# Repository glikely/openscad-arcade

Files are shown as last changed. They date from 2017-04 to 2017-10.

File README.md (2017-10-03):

# OpenSCAD Arcade Modeling

This project contains models for designing and building arcade cabinets.

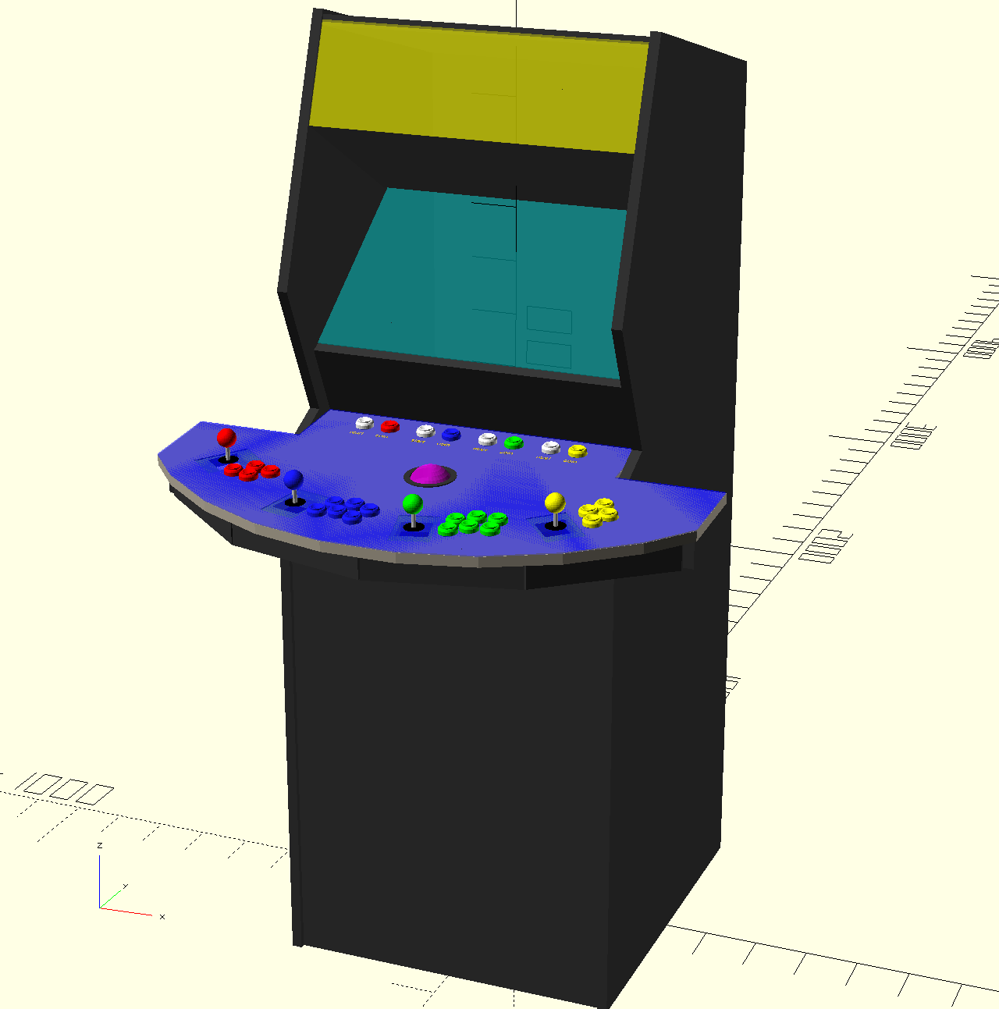
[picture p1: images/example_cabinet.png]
Arcade Panel


## Features

- Simple models for arcade controls: buttons, joysticks and trackballs
- Automatic generation of cutouts on control panel where controls are placed
- Support for multi layer control panel construction. ie. an MDF panel with an
  acrylic top sheet.
- Configurable for multiple players
- Countersunk joystick mounting for completely flat panels
- Output of .dxf files for use on a laser cutter.

## Build instructions

Installing OpenSCAD and opening the .scad files in this project should be all you
need to do to view the models.
You can get the latest release of OpenSCAD on the OpenSCAD website:
http://www.openscad.com

## Viewing the models

All of the model files can be viewed directly in OpenSCAD to see
examples of the models. The following libraries are included in this
repo:

- [controls.scad](controls.scad) - Models of common arcade controls.
  Currently implements a generic joystick, 28mm arcade buttons, and the
  Ultimarc U-Trak trackball. Also implements the concept of "control
  clusters" which is a set of controls clustered together in a specific
  orientation. ex. The joystick and buttons for a single player.
- [control_panel.scad](control_panel.scad) - Creates a control panel
  from one or more sheet materials (ie. MDF, perspex, etc) and places a
  configurable number of control clusters and start/coin buttons.
- [control_box.scad](control_box.scad) - Designs a custom enclosure box
  around a control panel generated by control_panel.scad.
- [cabinet.scad](cabinet.scad) - Simple model of a full size arcade
  cabinet using control_box and control_panel. Fun fact: model is based
  on a vintage "Track & Field" machine.

## Creating your own project

[example_2player_box.scad](example_2player_box.scad) shows how you can
use this library for your own custom arcade control box. To create your
own project, copy this file and add your new project to the Makefile.
When you type 'make', OpenSCAD will output a .dxf file with the layers
needed to lasercut your custom panel. (As-yet untested. You have been
warned!)

## Using the output

This project outputs design files that can be either directly laser cut on
materials (ex. acrylic & MDF),
or used to create cutting guides for materials that cannot be laser cut (ex.
plywood).
Viewing a project file (see example_*.scad) in OpenSCAD will show the 3D model.
To produce manufacturing artifacts change the value of OUTPUT_MODE to either
"lasercut" or "dimensions".

## TODO

The following features still need to be implemented

- PDF output of control panel layout to be used as template for graphics design
- Flattened layout of cabinet panels to use as cutting guide
- Support for side mounted pinball buttons
- Model "spinner" controls
- Model coin slots/door
- Model control boards and mounts
- Model speakers
- Add mounting holes for joysticks
- Allow vertical/horizontal/angle adjustment on control cluster placement instead
  of fixed by the formula.
- Allow 2 rows of control clusters

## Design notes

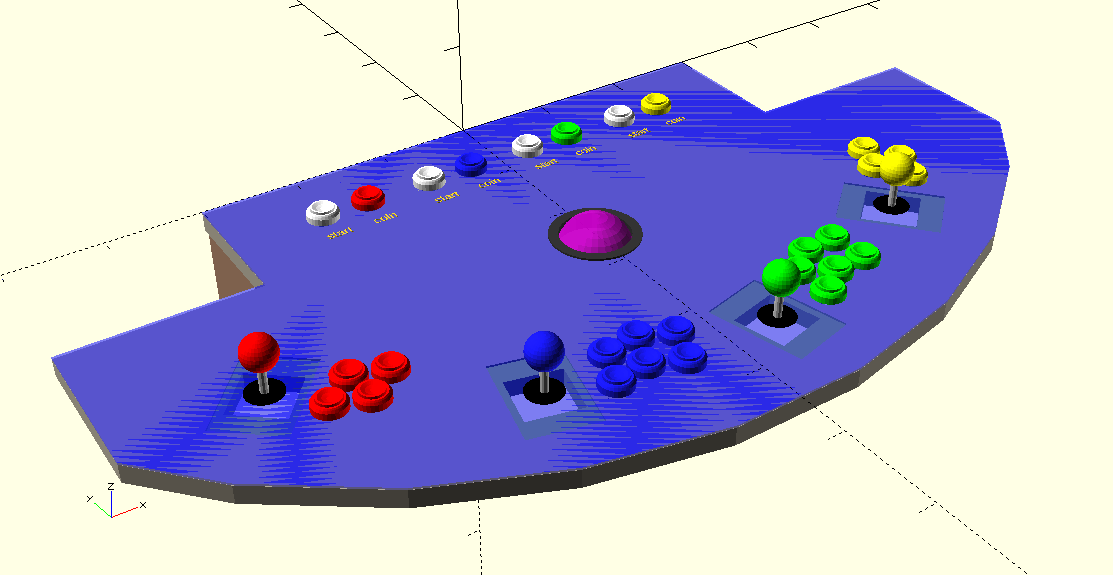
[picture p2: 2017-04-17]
images/example_panel.png

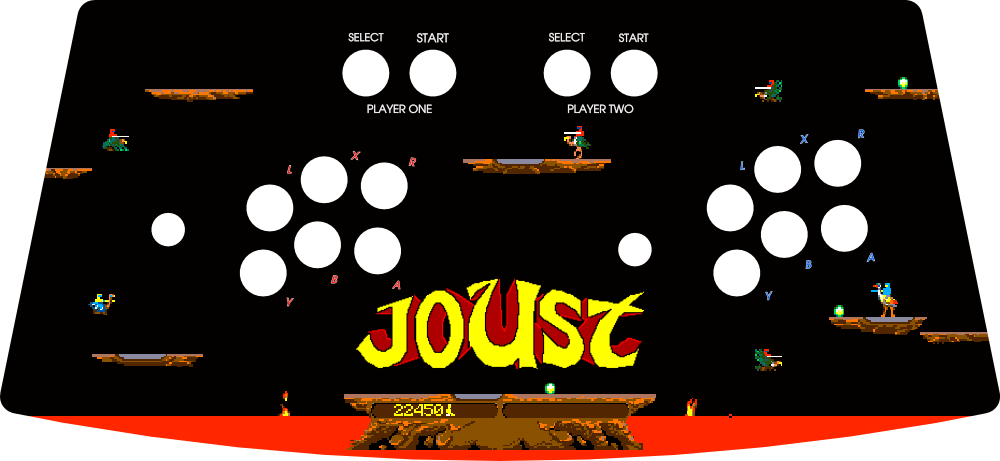
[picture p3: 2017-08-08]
2player_project/example_2player_box-vinyl-supernes.png

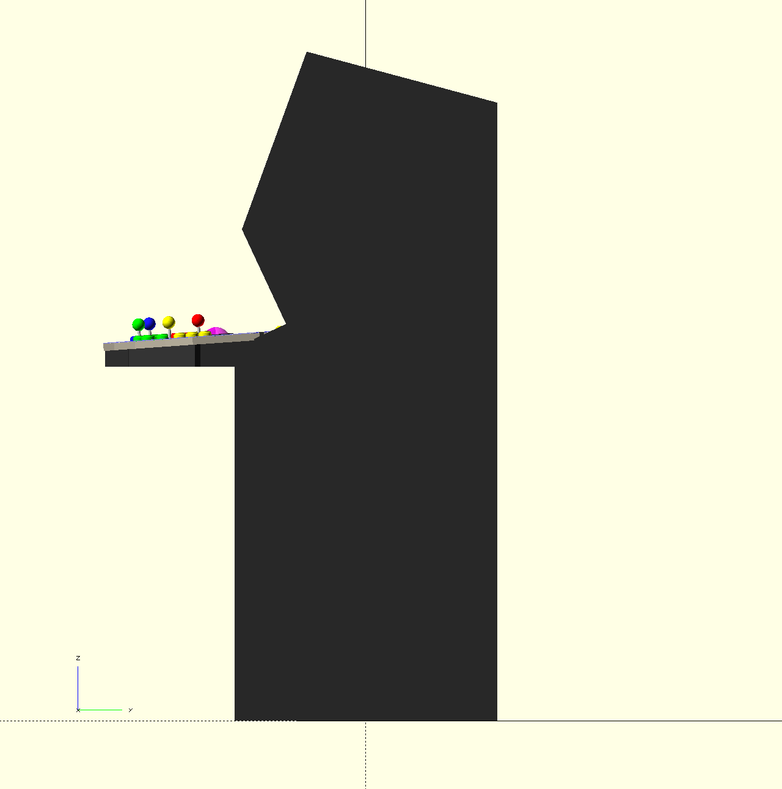
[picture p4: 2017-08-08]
2player_project/example_cabinet_side.png

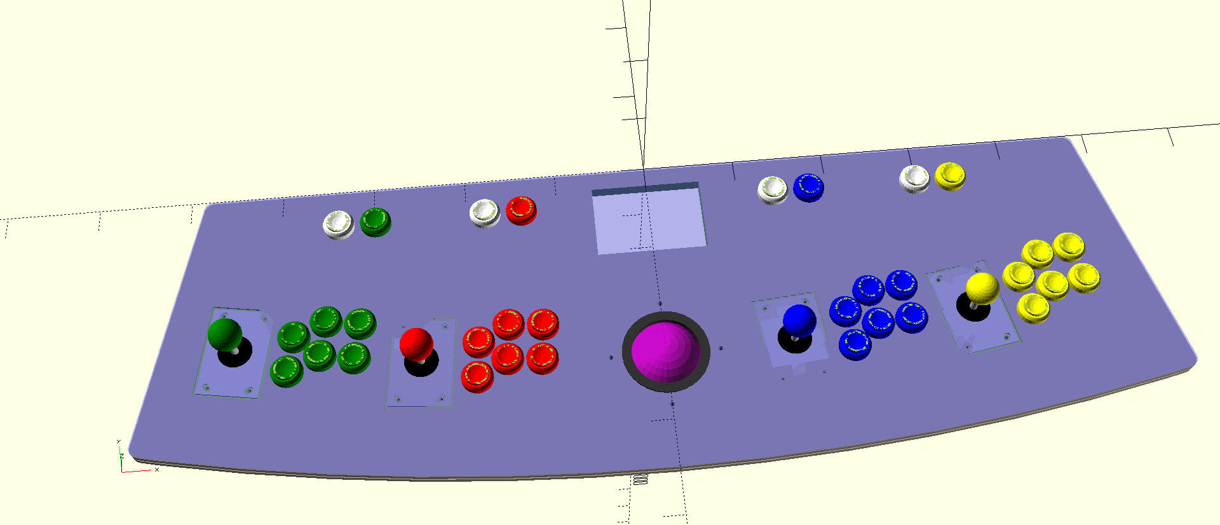
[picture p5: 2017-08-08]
2player_project/example_4player_box.png

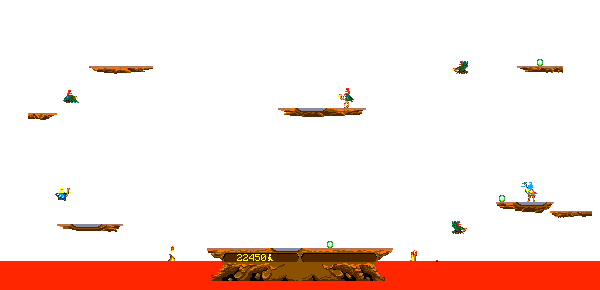
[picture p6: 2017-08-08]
2player_project/joust arcade panel.png

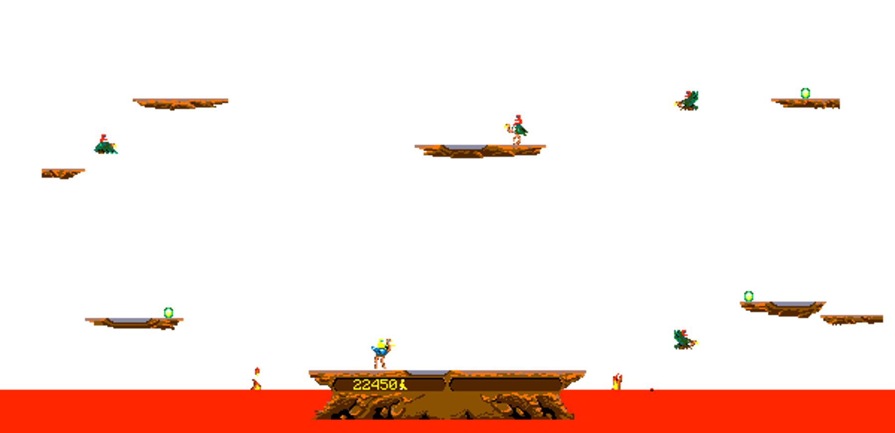
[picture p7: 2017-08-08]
2player_project/joust arcade panel x3.png

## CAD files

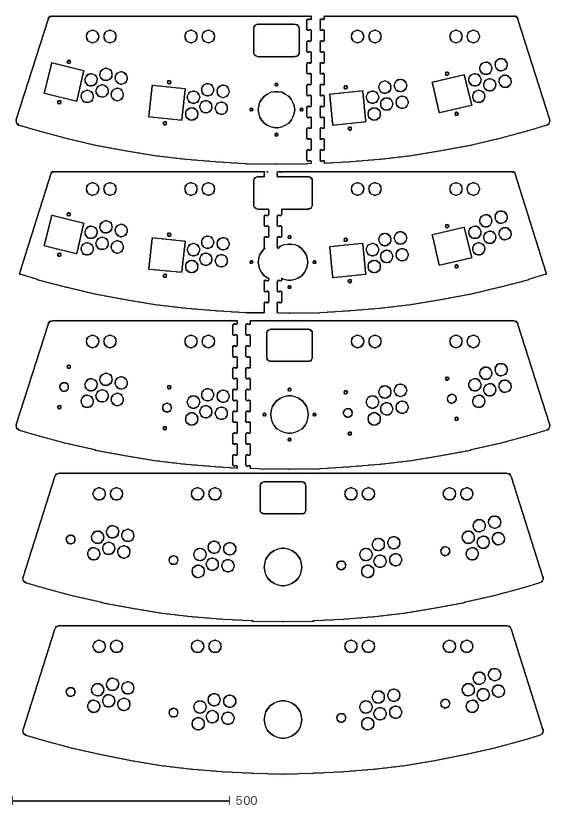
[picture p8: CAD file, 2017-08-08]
4player_project/example_4player_box-lasercut.dxf
1224.6 x 1740.0

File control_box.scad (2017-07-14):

include <materials.scad>
use <control_panel.scad>
use <utility.scad>

module panel_box(angle, size, inset, r, pc)
{
	curve_origin = r-size[1];
	front_edge = r ? sqrt(pow(r,2) - pow(size[0]/2,2))-curve_origin : size[1];
	back_edge = inset ? inset[1] : 0;
	side_angle = r ? asin((size[0]/2)/r) : 0;
	inset_radius = side_angle ? (curve_origin+back_edge)/cos(side_angle) : 0;
	back_width = side_angle ? 2*(curve_origin+back_edge)*sin(side_angle) : size[0];

	// Place the control panel. Angle is used to tilt it forward slightly
	rotate([angle,0,0]) panel(size=size, inset=inset, r=r, pc=pc);

	// Skirting
	color(BlackPaint) difference() {
		translate([0,0,-size[2]]) {
			// Back wall
			if (inset)
				translate([-inset[0]/2,-mdf_thick*1.5,0])
					cube([inset[0], mdf_thick, size[2]]);
			else
				translate([-back_width/2+mdf_thick*0.5,-mdf_thick*1.5,0])
					cube([back_width-mdf_thick*1, mdf_thick, size[2]]);
			mirror_dup([1,0,0]) {
				if (inset) {
					// Inset walls
					translate([-inset[0]/2,-inset[1]-(mdf_thick*1.5),0])
						cube([mdf_thick, inset[1], size[2]]);
					// Back side walls
					translate([-(back_width-mdf_thick)/2,-inset[1]-(mdf_thick*1.5),0])
						cube([(back_width-inset[0])/2,mdf_thick,size[2]]);
				}
				// Side walls
				if (r) translate([10, curve_origin, 0])
					rotate([0,0,-side_angle])
						translate([0, mdf_thick/2-r, 0])
							cube([mdf_thick, r-inset_radius-mdf_thick, size[2]]);
				else translate([-(size[0]-mdf_thick)/2,-front_edge+mdf_thick/2,0])
					cube([mdf_thick, front_edge-back_edge-mdf_thick, size[2]]);
			}
			// Front Edge
			translate([-size[0]/2+mdf_thick*1.5,-front_edge+mdf_thick/2,0])
				cube([size[0]-mdf_thick*3, mdf_thick, size[2]]);
		}
		// Trim the box for the angle of the control panel.
		rotate([angle,0,0])
			translate([-size[0]/2-0.1,-size[1]-0.1,-mdf_thick-plex_thick])
				cube([size[0]+0.2, size[1]+0.2, 1000]);
	}
}

pconfig = [[6, "red", "sega2", true],[6, "blue", "sega2", true]];
//panel_box(angle=4, size=[900,400,100],inset=[602,150]);
translate([-300,0])
	panel_box(angle=4, size=[500,350,100], inset=[300,150], pc=pconfig);
translate([+300,0])
	panel_box(angle=4, size=[500,350,100], pc=pconfig);
translate([-300,500])
	panel_box(angle=4, size=[500,350,100], inset=[300,150], r=1000, pc=pconfig);
translate([+300,500])
	panel_box(angle=4, size=[500,350,100], r=1000,  pc=pconfig);

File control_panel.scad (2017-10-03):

include <materials.scad>
use <utility.scad>
use <controls.scad>
use <dimlines.scad>

/**
 * panel_profile() - Creates a 2D outline of the control panel
 *
 * size: array of [width,height] describing the size of the panel
 * inset: (optional) array of [width,height] describing dimensions
 *        of the top edge of the panel if needed to fit inside a
 *        cabinet that is narrower than the control panel.
 * r: (optional) Radius of circle for a curved front control panel
 * corner: radius of corners on control panel, both for aesthetics
 *         and limitations of manufacturing process (ie. when using
 *         router to cut out the panel.
 */
module panel_profile(size, inset, r, corner=10, mount_angle, action="profile")
{
	// Calculate the front and back edge locations of the centre section
	curve_origin=r-size[1];
	back = inset ? inset[1] : 0;
	front = r ? sqrt(pow(r,2)-pow(size[0]/2,2)) - curve_origin : size[1];
	keystone = r ? (back+curve_origin)/(front+curve_origin) : 1;
	delta = r ? (size[0]/2)*(1 - (back+curve_origin)/(front+curve_origin)) : 0;
	panel_arc = r ? asin((size[0]/2)/r)*2 : 0;

	if (action == "profile") round_corners(corner) {
		// Main block of panel. Might be trapezoidal
		polygon ([[-size[0]/2,-front], [size[0]/2,-front],
		          [size[0]/2-delta,-back], [-size[0]/2+delta,-back]]);

		// Optional curved front
		if (r) intersection() {
			//echo(str("Panel Arc: ", panel_arc, "°"));
			translate([0,curve_origin,0]) circle(r,$fa=2);
			translate([-size[0]/2, -size[1]])
				square([size[0],size[1]-front+0.1]);
		}

		// Optional inset
		if (inset) {
			// Inset part of the panel
			translate([-inset[0]/2,-inset[1]-0.1,0])
				square([inset[0],inset[1]+0.1]);
		}
	}

	if (action == "frame") {
		height = size.z - panel_depth();
		ffront = size[1] - 33;
		a = [size[0]/2-delta-10, -back];
		b = [a.x+(front-mdf_thick*2.25-back)*tan(panel_arc/2), -front+mdf_thick*2.25];
		c = [b.x-(ffront+b.y)/tan(panel_arc/2), -ffront];
		polygon ([[-a.x,a.y],[-b.x,b.y],[-c.x,c.y],c,b,a]);

		// Print out the frame board dimensions
		side_len = sqrt(pow(b.x-a.x,2)+pow(b.y-a.y,2));
		frontlr_len = sqrt(pow(c.x-b.x,2)+pow(c.y-b.y,2));
		echo("Frame board dimensions");
		echo(str("Rear: length=", a.x*2, "mm ",
		               "height=", height, "mm ",
		               "mitre=", (90-panel_arc/2)/2, " ",
		               "slope=", mount_angle));
		echo(str("Side: length=", side_len, "mm ",
		         "height(top,bottom)=", height, ",", height - tan(mount_angle) * (-b.y),"mm ",
		         "mitre=", (90-panel_arc/2)/2, ",", 90/2, " deg ",
		         "slope=", atan(tan(mount_angle)*cos(panel_arc/2)), " ",
		         "bevel=", atan(tan(mount_angle)*sin(panel_arc/2))));
		echo(str("Front L/R: length=", frontlr_len, "mm ",
		         "height(top,bottom)=", height - tan(mount_angle) * (-b.y), ",", height - tan(mount_angle) * (-c.y),"mm ",
		         "mitre=", (90/2), ",", panel_arc/2/2, " deg ",
		         "slope=", atan(tan(mount_angle)*sin(panel_arc/2)), " ",
		         "bevel=", atan(tan(mount_angle)*cos(panel_arc/2))));
		echo(str("Front C:   length=", c.x*2, "mm height=", height - tan(mount_angle) * (-c.y), "mm ",
		         "mitre=", panel_arc/2/2, " slope=", mount_angle));
	}

	if (action == "dimensions") {
		// Angled Corners
		if (r) {
			panel_arc = asin((size[0]/2)/r)*2;
			mirror_dup([1,0,0]) {
				translate([0,curve_origin]) rotate([0,0,-90+panel_arc/2]) {
					translate([r,0]) {
						translate([-5,0]) line(18);
						rotate([0,0,90]) translate([-5,0])
							line(18);
					}
					translate([(size.x/2-delta)/sin(panel_arc/2)-10,0])
						line(13);
				}
				translate([size.x/2-delta-3, 0]) line(13);
			}
		}

		// Full panel width
		mirror_dup([1,0])
			translate([size.x/2,-size.y-25])
				rotate([0,0,90]) line(size.y-front+25);
		translate([-size.x/2,-size.y-20]) dimensions(size.x);
		// Angled panel width
		if (delta) {
			mirror_dup([1,0]) translate([size.x/2-delta,0])
				rotate([0,0,90]) line(25);
			translate([-size.x/2+delta,20])
				dimensions(size.x-delta*2);
		}

		// Full panel height
		if (r) {
			translate([size.x/2+5,-front]) line(25);
			translate([size.x/4,-size.y]) line(size.x/4+50);
			translate([size.x/2+25,-front]) rotate([0,0,90])
				dimensions(front);
		} else {
		}
		translate([size.x/2-delta,0]) line(delta+50);
		translate([size.x/2,-size.y]) line(50);
		translate([size.x/2+45,-size.y]) rotate([0,0,90]) dimensions(size.y);
	}
}

module frame_extrude(frame_height, frame_thickness=21)
{
	translate([0,0,-frame_height]) linear_extrude(frame_height, convexity=10) difference() {
		children();
		offset(-frame_thickness) children();
	}
}

/* Some canned control cluster layouts */
player_config_1 = [[8, "red", "sega2", true]];
player_config_2 = [[6, "red", "sega2", true],
                   [6, "blue", "sega2", true]];
player_config_2t =[[6, "red", "sega2", true],
                   [0, "purple", "trackball", false],
                   [6, "blue", "sega2", true]];
player_config_3 = [[6, "red", "sega2", true],
                   [6, "blue", "sega2", true],
                   [6, "yellow", "sega2", true]];
player_config_4 = [[4, "red", "sega2", true],
                   [6, "blue", "sega2", true],
                   [6, "green", "sega2", true],
                   [4, "yellow", "sega2", true]];
player_config_4t =[[4, "red", "sega2", true],
                   [6, "blue", "sega2", true],
                   [6, "purple", "trackball2", false],
                   [6, "green", "sega2", true],
                   [4, "yellow", "sega2", true]];

module panel_controls(size, inset, r, action="add",
                      start_colour="white", pc=player_config_4,
                      coin_spacing=40, keepout_border=mdf_thick,
                      cluster_ypos=125, cpu_window=false)
{
	// '275' is loosely the width of a single control cluster.
	cluster_max_width=275;
	panel_arc = asin((size[0]/2)/r)*2;

	curve_origin=r-size[1];
	num_players = len(pc);

	// Values for control cluster placement
	placement_width = size[0] - cluster_max_width;
	spacing = num_players > 1 ? placement_width/(num_players-1) : 0;

	// Values for start/select button placement
	start_ypos = -(keepout_border+28);
	start_spacing = inset ? (inset[0]-coin_spacing*2)/num_players : spacing;

	// CPU Board Window
	if (cpu_window) translate([0,-keepout_border-10])
		cpu_96boards(action=action);

	// Game Controls
	for (idx=[0:len(pc)-1]) if (pc[idx]) {
		p = pc[idx];
		offset = idx - (num_players-1)/2; // idx adjusted to center == 0
		if (r) {
			// Calculate the angle between control clusters, taking into
			// account the total panel width (on the curve), keeping the
			// clusters away from the sides, and the number of clusters
			// to place
			arc_length = ((2*PI*(r-cluster_ypos))*(panel_arc/360)) - cluster_max_width;
			arc_angle = 360 * arc_length/(2*PI*(r-cluster_ypos));
			cluster_angle = num_players > 1 ? arc_angle/(num_players-1) : 0;
			player_angle = cluster_angle * offset;
			start_xpos = (curve_origin-start_ypos)*tan(player_angle);

			// Place start/select buttons
			if (p[3] && !inset) translate([start_xpos, start_ypos, 0]) {
				translate([-coin_spacing/2,0,0])
					button(color=start_colour, action=action, label="select");
				if (coin_spacing)
					translate([coin_spacing/2,0,0])
						button(color=p[1], action=action, label="start");
			}

			translate([0,curve_origin]) rotate([0,0,player_angle])
				translate([0,-r+cluster_ypos]) {
					control_cluster(action=action,
					                max_buttons=p[0], color=p[1],
					                layout_name=p[2]);
				}

			if (action=="dimensions") translate([0,curve_origin])
				rotate([0,0,player_angle-90])
					translate([curve_origin-10,0]) {
						line(size[1]+20);
						translate([50,0])scale_text()
							text(str("Angle: ", player_angle, "°"), valign="bottom");
					}
		}

		// Player Start buttons
		if (p[3] && (!r || inset)) {
			start_xpos = start_spacing*offset;
			translate([start_xpos-coin_spacing/2, start_ypos])
				button(color=start_colour, action=action, label="select");
			if (coin_spacing) translate([start_xpos+coin_spacing/2, start_ypos])
				button(color=p[1], action=action, label="start");
		}

		if (!r) {
			translate([offset*spacing, -size[1]+cluster_ypos]) {
				control_cluster(action=action,
						max_buttons=p[0], color=p[1],
						layout_name=p[2]);
			}
		}
	}
}

module inset_profile(inset)
{
	minkowski() {
		difference() {
			square(10000, center=true);
			children();
		}
		circle(inset);
	}
}

layer_gap = 0.01;
default_layers = [
	[[0,0,1,.3], plex_thick, 0], // 3mm Perspex topsheet
	[[0,0,0], layer_gap*3, 0], // Vinyl Graphic Overlay
	[FiberBoard, 6, 0, -90],   // MDF Top (6mm)
	[FiberBoard, 2, -8,-18], // MDF Middle (2mm) with t-moulding groove
	[FiberBoard, 6, 0, 80],   // MDF Bottom (6mm)
];

function layer_depth(layers=default_layers, n, i=0) =
		(i < len(layers)) && (n != i) ?
			layers[i][1] + layer_depth(layers, n, i+1) :
			0;
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

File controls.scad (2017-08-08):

include <materials.scad>
use <dimlines.scad>
use <utility.scad>

function panel_depth() = $panel_depth ? $panel_depth : 17;
function panel_window_depth() = $panel_window_depth ? $panel_window_depth : plex_thick;
function panel_mount_depth() = $panel_mount_depth ? $panel_mount_depth : plex_thick;

module button(color="red", action="add", label)
{
	// Parameters
	screw_diameter = 23.8;
	screw_length = 31.2;
	button_diameter = 23.8;
	button_height = 12.6;
	switch_size=[6,24,18];
	fixingring_height = 10;
	fixingring_diameter = 33;

	// The button model
	if (action=="add") {
		color(color) {
			translate([0,0,-screw_length])
				cylinder(r=screw_diameter/2,h=screw_length);
			difference() {
				intersection() {
					cylinder(r=33.6/2,h=10.4);
					translate([0,0,-2])
						sphere(38/2);
				}
				translate([0,0,-1])
					cylinder(r=25/2,h=12);
			}

			translate([0,0,-screw_length])
				cylinder(r=screw_diameter/2,h=screw_length);
			difference() {
				cylinder(r=button_diameter/2,h=button_height);
				translate([0,0,30])
					sphere(40/2);
			}
		}

		// Fixing Ring
		color(BlackPaint) translate([0, 0, -panel_depth()-fixingring_height]) {
			difference() {
				cylinder(r=fixingring_diameter/2, h=fixingring_height);
				translate([0,0,-0.1])
					cylinder(r=screw_diameter/2+0.1,
					         h=fixingring_height+0.2);
			}
		}

		translate([0, 0, - (screw_length + switch_size[2]/2 + 1)])
			color(BlackPaint)
				cube(switch_size, center=true);
	} else if (action=="remove") {
		// Dimensions for mounting hole. Right through all the layers
		translate([0,0,-(screw_length)]) {
			cylinder(r=28/2, h=screw_length+button_height);
			cylinder(r=(fixingring_diameter+5)/2, h=10); // countersink for fixing ring
		}
	} else if (action=="dimensions") {
		circle_center(radius=28/2);
		if (label) translate([0,28/4,0]) scale_text()
			text(label, size=15, valign="center", halign="center");
	}
}

module sanwa_jlf_8s(color="red", action="add")
{
	shaft_len = 27.5+31.8+3.9;
	plate = [53,72,1.6];
	ear_inset = 8;
	ears = [53,107,1.6];
	bolthole_spacing = 107/2-6;
	bolthole_radius = 7/2;
	box = [76,61,33];
	tophole_radius = 10;

	if (action=="add") {
		// Ball top
		color(color) {
			translate([0,0,27.5+(32/2)]) sphere(34/2);
		}
		// shaft
		color("silver") translate([0,0,-shaft_len+28]) cylinder(r=4, h=shaft_len);

		// mounting plate
		color("silver") translate([0,0,-panel_depth()-plate.z]) {
			translate([0,0,ear_inset])
				cube(plate, center=true);
			difference() {
				cube(ears, center=true);
				cube(plate, center=true);
				translate([0,bolthole_spacing])
					cylinder(r=bolthole_radius, h=plate.z*2);
				translate([0,-bolthole_spacing])
					cylinder(r=bolthole_radius, h=plate.z*2);
			}
		}

		// Electronics box
		color(BlackPaint) translate([0,0,-panel_depth()-plate.z+ear_inset-(box[2]/2)])
			cube(box, center=true);

		// Dust Cover Disc
		color("black") cylinder(r=18, h=0.5);

	} else if (action=="remove") translate([0,0,-panel_depth()]) {
		// The cutouts for the joystick
		// Hole for the joystick box
		translate([0,0,ear_inset-(box[2])/2])
			cube([box[0],plate[1],box[2]], center=true);
		// Mounting holes
		translate([0,bolthole_spacing,0])
			cylinder(r=bolthole_radius, h=panel_depth()-panel_mount_depth());
		translate([0,-bolthole_spacing,0])
			cylinder(r=bolthole_radius, h=panel_depth()-panel_mount_depth());

		// Round hole for joystick shaft
		translate([0,0,0]) cylinder(r=tophole_radius, h=panel_depth());
	} else if (action=="dimensions") {
		circle_center(radius=tophole_radius);
		// Mounting holes
		translate([0,bolthole_spacing,0])
			circle_center(radius=bolthole_radius);
		translate([0,-bolthole_spacing,0])
			circle_center(radius=bolthole_radius);
	}
}

module joystick(color="red", action="add")
{
	shaft_len = 27.5+31.8+3.9;
	plate = [65,97,1.6];
	boltholes = [22,41];
	box = [60,55,31.8];
	ears = [20,box[1]+12*2,10];
	tophole_radius = 10;

	if (action=="add") {
		translate([0,0,-panel_mount_depth()]) {
			// Ball top
			color(color) {
				translate([0,0,27.5+(32/2)]) sphere(34/2);
			}
			// shaft
			color("silver") translate([0,0,-shaft_len+28]) cylinder(r=4, h=shaft_len);

			// mounting plate
			color("silver") translate([0,0,-2/2]) difference() {
				cube(plate, center=true);
				fourcorners() translate(boltholes) rotate([0,0,45]) hull() {
					translate([0,-2,-1]) cylinder(r=3, h=plate.z*2);
					translate([0, 2,-1]) cylinder(r=3, h=plate.z*2);
				}
			}

			// Electronics box
			color(BlackPaint) translate([0,0,-2-(box[2]/2)])
				cube(box, center=true);
			color(BlackPaint) translate([0,0,-2-(ears[2]/2)])
				cube(ears, center=true);
		}
		// Dust Cover Disc
		color("black") cylinder(r=18, h=0.5);

	} else if (action=="remove") translate([0,0,-panel_mount_depth()]) {
		// The cutouts for the joystick
		// Mount place profile
		translate([0,0,-2/2]) cube([plate[0]+5, plate[1]+5, 2], center=true);
		// Hole for the joystick box
		translate([0,0,-(box[2]/2 + 3)])
			cube([box[0],box[1],box[2]+6], center=true);
		// Mounting holes
		translate([0,0,-(box[2] + 6)]) fourcorners()
			translate([22,41]) cylinder(r=2, h=box[2]+6);
		translate([0,0,-(box[2]/2 + 3)])
			cube([ears[0],ears[1],box[2]+6], center=true);

		// Round hole for joystick shaft
		translate([0,0,-2/2]) cylinder(r=tophole_radius, h=10);
	} else if (action=="dimensions") {
		circle_center(radius=tophole_radius);
		fourcorners() translate([22,41]) circle_center(radius=2);
	}
}

// utrak_mounts() - private utility for placing mounting holes
module utrak_mounts(spacing = 81.32)
{
	d=sqrt(2*pow(spacing/2,2));
	for (p=[[d,0],[-d,0],[0,d],[0,-d]])
		translate(p)
			children();
}

module utrak_trackball(action="add")
{
	box_width = 145;
	box_height = 53;
	diag_length = 176;
	diag_width = 126.5;
	hole_spacing = 81.32;
	hole_radius = 6/2;
	housing_height = 19;
	housing_radius = 83/2;
	bezel_radius = 86/2;
	bezel_height = 8;
	flang_height = 2;
	flang_radius = housing_radius + 5;

	if (action=="add") translate([0,0,-panel_depth()]) {
		// Housing
		color(BlackPaint) difference() {
			translate([0,0,-box_height/2-0.1]) intersection() {
				cube([box_width,box_width,box_height], center=true);
				rotate([0,0,45])
					cube([diag_width,diag_length,box_height], center=true);
			}
			// Bolt holes
			utrak_mounts()
				translate([0,0,-box_height-0.1])
					cylinder(r=hole_radius, h=box_height+0.2);
		}
		color(BlackPaint) difference() {
			union() {
				cylinder(r=housing_radius,h=housing_height);
				if (panel_depth() <= 17.5)
					translate([0,0,19-flang_height])
						cylinder(r=flang_radius,h=flang_height);
			}
			translate([0,0,-0.1]) {
				cylinder(r=housing_radius-2,h=housing_height+0.1-flang_height);
				cylinder(r=housing_radius-5,h=housing_height+0.2);
			}
		}
		// Trackball
		translate([0,0,0]) color([1,0,1,0.75]) sphere(3/2 * 25.4);
	} else if (action=="remove") {
		translate([0,0,-panel_depth()-box_height/2]) intersection() {
			cube([box_width,box_width,box_height], center=true);
			// FIXME - The following two lines should be
			// uncommented, but it confuses OpenSCAD. In the mean
			// time leave it out and live with a larger than
			// necessary inset profile
			//rotate([0,0,45])
			//	cube([diag_width+5,diag_length+5,box_height], center=true);
		}
		translate([0,0,-panel_depth()]) {
			cylinder(r=housing_radius, h=panel_depth());
			// Bolt holes
			utrak_mounts()
				cylinder(r=hole_radius, h=panel_depth()-panel_mount_depth());
		}
		translate([0,0,-bezel_height])
			cylinder(r=bezel_radius, h=bezel_height);
	} else if (action=="dimensions") {
		circle_center(housing_radius, size=housing_radius/4);
		utrak_mounts()
			circle_center(hole_radius);
		translate([0,10]) scale_text() text("Trackball", halign="center");
	}
}

module cpu_96boards(action="add", margin=10, bs=[85,54])
{
	if (action == "add") {
		translate([-bs.x/2,-bs.y,-(panel_depth()+10)])
			color("green") difference() {
				cube([bs.x, bs.y, 1]);
				translate([5,5,-0.1]) cylinder(r=2,h=2);
				translate([bs.x-5,5,-0.1]) cylinder(r=2,h=2);
				translate([5,bs.y-5,-0.1]) cylinder(r=2,h=2);
				translate([bs.x-5,bs.y-5,-0.1]) cylinder(r=2,h=2);
			}
		translate([-bs.x/2,-bs.y*2-10,-(panel_depth()+10)])
			color("green") difference() {
				cube([bs.x, bs.y, 1]);
				translate([5,5,-0.1]) cylinder(r=2,h=2);
				translate([bs.x-5,5,-0.1]) cylinder(r=2,h=2);
				translate([5,bs.y-5,-0.1]) cylinder(r=2,h=2);
				translate([bs.x-5,bs.y-5,-0.1]) cylinder(r=2,h=2);
			}
	} else if (action=="remove") {
		translate([0,-bs.y/2,-(panel_depth())])
			linear_extrude(panel_depth() - panel_window_depth())
				offset(r=margin) square(bs, center=true);
	} else if (action=="dimensions") {
		scale_text() text("96Boards Display Window", halign="center");
		translate([0,-bs.y/2])
			cutlines() offset(r=margin) square(bs, center=true);
	}
}
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

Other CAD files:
cabinet.scad
dimlines.scad
example_2player_box.scad
example_4player_box.scad
joystick_adapters.scad
materials.scad
utility.scad

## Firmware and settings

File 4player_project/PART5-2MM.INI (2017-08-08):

[CreateTechnicsCodeMgr]
PrjHasModifyCFG=1
[Technics_Laser_Data]
ModifyTechCFG=0
LayersNumber=2
LayerColor_0=255
LayerColor_1=16711680
LayerColor_2=16711680
ExportRows=1
ExportColumns=1
ExportRowSpace=0.00000
ExportColumnSpace=0.00000
ExportRowCW=0.00000
ExportColumnCW=0.00000
LogicOrgPositionX=117.88182
LogicOrgPositionY=672.67443
LogicOrgPositionZ=-9999999.00000
AtOnceExport=1
IsTwoLaserWorking=1
TableZeroPositionX=0.00000
TableZeroPositionY=0.00000
OutputTimes=1
DelayTime=0
FeedLength=0.00000
FeedSpeed=5.00000
FeedDelayTime=0
MinX=117.88182
MaxX=689.13882
MinY=349.15843
MaxY=672.67443
ChangeSerialNo=0
ArrayMinX=117.88182
ArrayMaxX=689.13882
ArrayMinY=349.15843
ArrayMaxY=672.67443
ClipBoxPower=40.00000
ClipBoxPower2=40.00000
ClipBoxOffsetLen=2.00000
ClipBoxSpeed=25.00000
AlignMachineZPos=0.00000
RouteLength=0.00000
RoutePointNumber=0
OffsetLaserPower=0.00000
OffsetWorkSpeedPer=1.00000
ZHeightForLaserFocus=0.00000
OneWorkNeedTimes=0
TotalWorkTimes=0
[CoordSystem_0]
LogicOrgPosition1=117.88182
LogicOrgPosition2=672.67443
LogicOrgPosition3=-9999999.00000
SPLITBLOCK_NUMBER=2
SPLITBLOCK_NUMBER_0=0.00000
SPLITBLOCK_NUMBER_1=100000.00000
[TechnicsLayers_7697781]
TechnicsMode=TECHNICS_LASERCUT
LaserCutConnerPower=30.00000
LaserCutWorkPower=90.00000
LaserCutConnerPower2=30.00000
LaserCutWorkPower2=50.00000
LaserCutFrequency=20000
LaserCutOptimizePathType=1
LaserCutInnerToOuter=1
LaserCutInnerToOuter2=0
LaserCutDownToUpper=0
LaserCutBlockHeight=150.00000
LaserCutAutoSetPathDir=0
LaserCutCicleMinSegNumber=36
LaserCutDisperseLength=0.10000
LaserCutCloseGapLength=0.00000
LaserCutOverlapLength=0.00000
LaserCutAdjustForClose=0
LaserCutQXEnterLength=0.00000
LaserCutDelayMoveTime=0.00000
LaserCutOpenGZDelayTime=0.00000
LaserCutOpenLaserDelayTime=0.00000
LaserCutCloseLaserDelayTime=0.00000
LaserCutDelayTimeAfterCloseLaser=0.00000
LaserCutOneAxisBackLashLength=0.00000
LaserCutTwoAxisBackLashLength=0.00000
LaserCutBackLashAddSpaceLength=8.00000
LaserCutBlowGasType=2
LaserCutAheadBlowGasTimes=0.00000
LaserCutNoCloseGasTimes=0.00000
LaserCutSpeed=9.50000
LaserCutGWAcc=200.00000
LaserCutGWTime=0.01000
LaserCutTrackSize=100
LaserCutLineLength=0.00000
SpaceCutLineLength=0.00000
bSpaceLineFirst=0
LaserCutAdjustMove=0
LaserCutAdjustMoveDelay=0.00000
LaserCutUpLen=0.00000
LaserCutCircleSpeedNum=6
LaserCutCircleSpeed0_MinR=0.00000
LaserCutCircleSpeed0_MaxR=0.55000
LaserCutCircleSpeed0_Speed=15.00000
LaserCutCircleSpeed1_MinR=0.55000
LaserCutCircleSpeed1_MaxR=1.05000
LaserCutCircleSpeed1_Speed=20.00000
LaserCutCircleSpeed2_MinR=1.05000
LaserCutCircleSpeed2_MaxR=1.55000
LaserCutCircleSpeed2_Speed=25.00000
LaserCutCircleSpeed3_MinR=1.55000
LaserCutCircleSpeed3_MaxR=2.05000
LaserCutCircleSpeed3_Speed=30.00000
LaserCutCircleSpeed4_MinR=2.05000
LaserCutCircleSpeed4_MaxR=3.05000
LaserCutCircleSpeed4_Speed=35.00000
LaserCutCircleSpeed5_MinR=3.05000
LaserCutCircleSpeed5_MaxR=4.05000
LaserCutCircleSpeed5_Speed=40.00000
GROUP_ROWS_0=1
GROUP_COLUMNS_0=1
GROUP_ROWSPACE_0=0.00000
GROUP_COLUMNSPACE_0=0.00000
GROUP_ROWCWSPACE_0=0.00000
GROUP_COLUMNCWSPACE_0=0.00000
GROUP_MINX_0=322.99364
GROUP_MAXX_0=830.25764
GROUP_MINY_0=299.90212
GROUP_MAXY_0=637.62512
[TechnicsLayers_255]
TechnicsMode=TECHNICS_LASERCUT
LaserCutConnerPower=20.00000
LaserCutWorkPower=60.00000
LaserCutConnerPower2=30.00000
LaserCutWorkPower2=50.00000
LaserCutFrequency=20000
LaserCutOptimizePathType=1
LaserCutInnerToOuter=1
LaserCutInnerToOuter2=0
LaserCutDownToUpper=0
LaserCutBlockHeight=150.00000
LaserCutAutoSetPathDir=0
LaserCutCicleMinSegNumber=36
LaserCutDisperseLength=0.10000
LaserCutCloseGapLength=0.00000
LaserCutOverlapLength=0.00000
LaserCutAdjustForClose=0
LaserCutQXEnterLength=0.00000
LaserCutDelayMoveTime=0.00000
LaserCutOpenGZDelayTime=0.00000
LaserCutOpenLaserDelayTime=0.00000
LaserCutCloseLaserDelayTime=0.00000
LaserCutDelayTimeAfterCloseLaser=0.00000
LaserCutOneAxisBackLashLength=0.00000
LaserCutTwoAxisBackLashLength=0.00000
LaserCutBackLashAddSpaceLength=8.00000
LaserCutBlowGasType=2
LaserCutAheadBlowGasTimes=0.00000
LaserCutNoCloseGasTimes=0.00000
LaserCutSpeed=30.00000
LaserCutGWAcc=200.00000
LaserCutGWTime=0.01000
LaserCutTrackSize=100
LaserCutLineLength=0.00000
SpaceCutLineLength=0.00000
bSpaceLineFirst=0
LaserCutAdjustMove=0
LaserCutAdjustMoveDelay=0.00000
LaserCutUpLen=0.00000
LaserCutCircleSpeedNum=6
LaserCutCircleSpeed0_MinR=0.00000
LaserCutCircleSpeed0_MaxR=0.55000
LaserCutCircleSpeed0_Speed=15.00000
LaserCutCircleSpeed1_MinR=0.55000
LaserCutCircleSpeed1_MaxR=1.05000
LaserCutCircleSpeed1_Speed=20.00000
LaserCutCircleSpeed2_MinR=1.05000
LaserCutCircleSpeed2_MaxR=1.55000
LaserCutCircleSpeed2_Speed=25.00000
LaserCutCircleSpeed3_MinR=1.55000
LaserCutCircleSpeed3_MaxR=2.05000
LaserCutCircleSpeed3_Speed=30.00000
LaserCutCircleSpeed4_MinR=2.05000
LaserCutCircleSpeed4_MaxR=3.05000
LaserCutCircleSpeed4_Speed=35.00000
LaserCutCircleSpeed5_MinR=3.05000
LaserCutCircleSpeed5_MaxR=4.05000
LaserCutCircleSpeed5_Speed=40.00000
GROUP_ROWS_0=1
GROUP_COLUMNS_0=1
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

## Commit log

2017-04-15 Initial design of arcade cabinet controls
    Commit a first cut of the arcade control panel. Just enough to
    lay out some controls on a dual layer panel.
    [controls.scad, panel.scad]
2017-04-15 Add cutouts for controls
    Add a 'cutouts' parameter to all the control placement modules which
    generates hole profiles when set to true, and use the new parameter
    to create cutouts for control placement.
    [controls.scad, materials.scad, panel.scad]
2017-04-15 Parameterize button count and make undermount a joystick property
    The joystick module needs to know the undermount value so the dust cover
    ring gets placed correctly. Therefore, pass undermount right through to
    the joystick and don't do the adjustment anywhere else.
    Also, put the button positions into an array so that a different button
    count can be selected for each control panel.
    [controls.scad, panel.scad]
2017-04-15 Parameterize player controls creation
    Use a for() loop for generating the user controls to make it easier to
    change the layout for a different number of players.
    [panel.scad]
2017-04-15 Add a trackball model
    Based on Ultimarc U-Trak arcade trackball. Can be mounted with or
    without bezel.
    [controls.scad, panel.scad]
2017-04-16 Paramaterize player layout config
    Change the panel layout code to be configurable for different player
    layouts and to place the correct number of player start buttons.
    [panel.scad]
2017-04-16 Add coin button option to panel layout
    The coin buttons can be placed beside the player start buttons. It uses
    the assigned player colour instead of white to distinguish between them.
    Start and coin pairs are placed close together so the grouping is clear.
    [panel.scad]
2017-04-17 Add a README.md file
    Start documenting this project with a README file. Lists how to use the project
    and a TODO list of features not yet implemented.
    [materials.scad, panel.scad]
2017-04-17 Added a model for a full cabinet
    Add a cabinet model based on an old machine I'm retrofitting with a new control
    panel. This model isn't parameterized in any way, so it may be of limited use
    for anyone designing a new cabinet.
    [cabinet.scad]
2017-04-17 Add rough skirting around control panel
    Adds rough skirting boards around the control panel. They aren't accurately cut
    and will need to be calculated properly before generating design files.
    [panel.scad]
2017-04-18 Move control panel box into separate module
    The control panel itself is logically separate from a box used to encase
    it. Some cabinet designs will forgo the box entirely. Others will
    consist of only the box. Split the box into a separate file entirely to
    show the difference.
    As part of spliting the box, also refactor the code generating the
    control panel. Parameterize the multilayer panel generation so that it
    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
    [cabinet.scad, control_box.scad, control_panel.scad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]
2017-04-18 Remove the globals for control panel layout
    The control panel module used a bunch of global values that made it
    difficult to change the size of a panel design. Remove the globals and
    start passing the values around as parameters instead. There is still
    some refactoring needed to get rid of the control placement angle.
    The multilayer panel code also got refactored to eliminate the explicit
    depth of each layer. Instead the function is called recursively to stack
    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
    [control_panel.scad]
2017-04-20 Add more control layout options and show examples
    Add support for multiple layout options for each control cluster and
    change the demo code to show a sample of each control option when
    viewing controls.scad in OpenSCAD. Each layout is given a name that is
    printed with the layout in the sample view.
    At the same time rename button_pad() to control_cluster() to reflect the
    new functionality.
    [control_panel.scad, controls.scad]
2017-04-20 control_panel: Pass size and inset as array
    Instead of passing each dimension separately, pass them as two arrays instead
    to make it easier when they need to be passed into several sub modules. This
    replaces with "width" and "depth" arguments with "size", and "cab_width" and
    "inset" with a single array named "inset".
    [control_panel.scad]
2017-04-20 Use strings for common colors
    No need to have special definitions for red, green, etc. Use the colour
    name strings that are already built into OpenSCAD.
    [control_panel.scad, controls.scad, materials.scad]
2017-04-20 Remove hard coded angles for control cluster layout
    Refactor the control cluster layout code to automatically calculate the
    needed angle based on the width of the panel and the radius of the front
    curve. Also fall back to straight across translation with the panel is
    created with a straight front.
    [control_panel.scad]
2017-04-20 Pass player config via the panel() module
    Make it easier to instantiate different control layouts by accepting a 'pc'
    argument to the panel() module.
    [control_panel.scad]
2017-04-21 Round the corners on the panel
    Rounded corners look better, and are also needed to model capabilities
    of cutting with a router or CNC.
    [control_panel.scad]
2017-04-21 Replace 'cutout' argument with 'action' on controls
    'cutout' was a boolean that indicated if the control is being added to the
    view, or if the control cutout outlines were needed for carving the control
    panel. However, a boolean is limiting because it doesn't allow for any other
    operations to be added to the module. Follow the lead of Jeremie Francois'
    excellent OpenSCAD tutorial[1] and rename the argument to 'action', with 'add'
    meaning the control itself and 'remove' meaning the negative space cutout. Also
    add 'guide' for creating a drilling guide for holes.
    [1] http://www.tridimake.com/2014/11/how-to-use-openscad-4-children-and.html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
    [control_panel.scad, controls.scad]
2017-04-22 Add bolt hole guides on trackball model
    The trackball "remove" action needs to indicate where bolt holes are
    located. Add them.
    [controls.scad]
2017-04-22 Angle the control panel sides when using a curved front
    Because it looks cool.
    [control_panel.scad]
2017-04-23 Place trackballs in the same way that joystick clusters are placed
    The trackball code was a special case that would only place the ball in
    the dead center of the control panel. Get rid of it and make use of the
    control_cluster() module ability to place trackballs in any of the
    player locations.
    [control_panel.scad]
2017-04-23 Fix control box to use size & inset arguments correctly
    The control_box module hasn't been updated since the control_panel was
    switched to using 'size' and 'inset' arguments instead of width, depth,
    cab_width, and inset. Therefore the box being generated didn't match the
    dimensions of the panel() module when created. Fix the code to at least
    get the right dimensions. It still needs to be fixed use the right
    outline profile, but at least the size is correct now.
    [control_box.scad]
2017-04-26 Fix placement of control clusters on curved panel
    The cluster placement code didn't correctly calculate the position of
    clusters on a curve, and wasn't very good at spacing to get maximum
    panel utilization. Fix the placement code to correctly calculate the arc
    length and angle between clusters for a curved board, and to use a
    defined value to place clusters as close to the sides as possible.
    [control_panel.scad]
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2017-04-26 Fix box construction to deal with angles and inset
    The box generation code wasn't handling the new panel shape. Rework the box generation for the new profile.
    [control_box.scad]
2017-04-26 Add fixing ring to button model
    The button model didn't include the fixing ring (otherwise known as a
    nut, arcade part vendors use weird names). Add it in.
    [controls.scad]
2017-04-26 Fix placement of angled sidewalls
    The sidewalls weren't very well placed. Adjust to fit the curved box more
    precisely.
    [control_box.scad]
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2017-04-28 Add 'dimensions' action to show manufacturing detail
    Replace the 'guide' action with 'dimensions' to add dimensional
    information to the drawing that is useful for manufacturing.
    [control_panel.scad, controls.scad, dimlines.scad]
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2017-05-06 Update dimlines to latest from github.com/glikely/dimlines
    Check in the latest dimlines.scad and fix up the users
    [controls.scad, dimlines.scad]
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2017-05-06 Add automatic output targets to the example
    Add to the makefile automatic generation of manufacturing file. Now when
    you type 'make', it will automatically generate .dxf and .svg files. The
    .dxf file can immediately be used by a laser cutter. The .svg file needs
    to be scaled to the correct page size.
    [example_2player_box.scad]
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2017-06-09 Remove 5mm tolerance from joystick cutouts
    The lasercutter is so precise that there is no need to add big tolerances to
    the cutouts. The joystick will fit without them.
    [controls.scad]
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2017-07-14 Add start/select bool to player config structure
    Add a start/select bool field to the player config structure so that player
    buttons don't get added for every single control structure. For example, often
    the trackball cluster doesn't need it's own start/select buttons.
    At the same time allow for empty slots in the player config table. This allows
    the config to add relative space between the control clusters. For example, not
    as much space is needed between a player cluster and a trackball as between two
    player clusters. Inserting more empty slots between two clusters effectively
    puts more weight on that spacing.
    [control_box.scad, control_panel.scad, example_2player_box.scad]
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2017-07-14 Overhaul start/select button placement logic
    Fix the start/select button placement so the buttons are lined up with the
    associated control cluster, and so it handles panel inset sections correctly.
    [control_panel.scad]
2017-07-14 Switch t-moulding layer to 2mm instead of 3mm
    3mm is too wide, the t-moulding doesn't stay in it.
    [control_panel.scad]
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2017-07-15 trival: Change a few line breaks
    Reflow some of the code to better fit onto 80 column terminals. Also fix one
    typo.
    [controls.scad]
2017-07-16 Add bezel profile to utrak trackball
    The utrak was missing a cutout for the top bezel. Add it.
    [controls.scad]
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2017-07-16 When drawing dimensions, don't use the acrylic top layer
    The top layer isn't very useful because it doesn't have all the holes. Draw
    dimensions using the first MDF layer.
    [control_panel.scad]
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2017-08-07 Change t-molding grove depth to 8mm
    10mm was a bit too large. Cut it down to 8mm
    [control_panel.scad]
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2017-08-07 Refactor panel depth calculations
    Refactor panel_multilayer to use a for() loop instead of recursive
    calls. This simplifies the code a bit. Also change the way layers are
    calculated. Subtract a margin of layer_gap height from the top and
    bottom of every layer so that control placement doesn't have to try and
    guess where margins need to be added. The controls can work on the layer
    heights as given, and the panel will subtract a margin so that rendering
    works correctly.
    [control_panel.scad, controls.scad]
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2017-08-08 Add jigsaw cuts to panel output
    Due to MDF panels not being wide enough, add some jigsaw cuts to the
    design so that the correct size panel can be built up from smaller
    panels. The jigsaw cuts fit together
    [control_panel.scad, utility.scad]
2017-08-08 Update control mounting hole sizes
    Fix some undersized holes and add hole center to joystick dimensions
    [controls.scad]
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2017-08-08 Add manufacturing output for the 4 player box
    MFG files used on 8 Aug 2017 to build the panel for a 4 player box. A
    few sizes need to be modified after cutting this design. The trackball
    hole was slightly too small, as was the joystick cutout. Those two
    parameters will be adjusted before the next time this panel is cut.
    [example_4player_box-lasercut.dxf]
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2017-08-08 Make all dimensions 2D objects
    Dimensions are 2D constructs, and are being output in an SVG file which
    can only handle 2D objects. It doesn't make sense for them to be
    generated as 3D objects when they immediately need to be projected back
    into 2D. Make all of dimlines create 2D objects so that generating
    output is easier and faster.
    [control_panel.scad, dimlines.scad]
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
